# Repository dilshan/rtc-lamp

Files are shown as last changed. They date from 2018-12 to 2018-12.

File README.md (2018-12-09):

# RTC based automatic LED lamp

This is real-time clock based automatic LED lamp which we originally designed to use as night light. This lamp can programmed to turn on and off at the specific time of the day. For example, it can program to turn on at 6 PM on each day and to turn off at 4 AM next day.

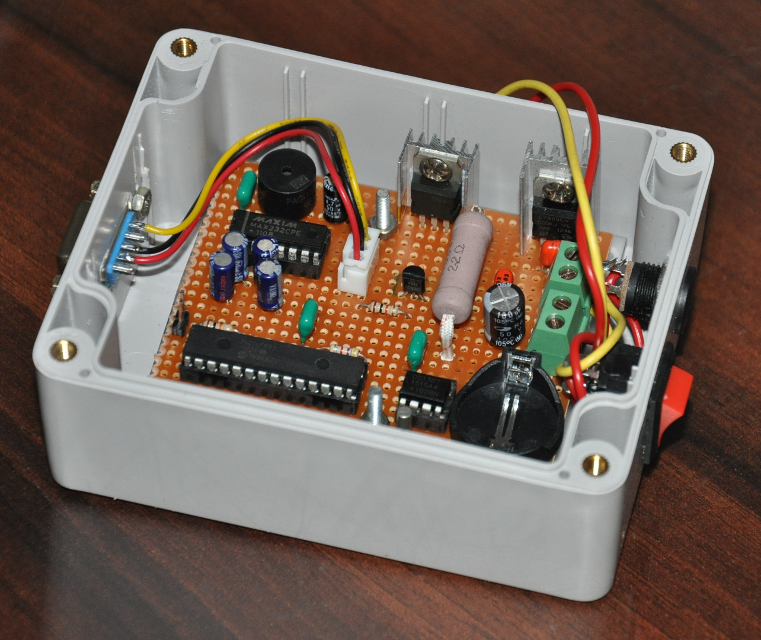
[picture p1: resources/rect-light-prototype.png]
Prototype version of LED lamp


The core component of this project is PIC16F883 MCU and it's firmware is developed using *MikroC Pro for PIC*. We select this MCU because of it's 7 KB flash memory, I2C, UART, E2PROM and built-in 8-bit and 16-bit timers. In this system we use DS1307 RTC because of it's availability in the market and lower external component count.

### LED module

This lamp is designed to work with commonly available 7W LED panels. In our prototype design we use 7W 24V warm-white LED module to test this system. To drive other LED modules change value of the R5 resistor of the current limiter circuit.

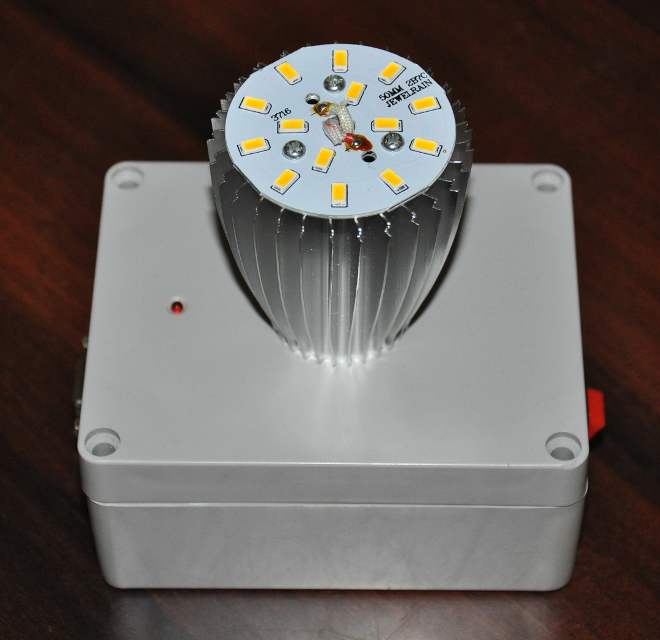
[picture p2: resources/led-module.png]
7W LED module used in prototype build


LED modules, heat-sink and lamp enclosures are now commonly available in the market but make sure to use good quality 24V - 28V LED module with this circuit. During our prototype we found lot of defective LED modules in the market.

### Battery backup

This unit is designed to work with 24V - 3A power supply unit. 3V button cell is required as back power source of DS1307 RTC. Supplied PCB is designed to work with *CR2025* or *CR2032* type button cells.

### Circuit assembly

For this project we use commonly available, less expensive electronic components and PCB is designed for "through-hole" type components. 

Both Q1 (STP55N06) and U4 (LM7805) required heatsinks. If heatsink is shared between both devices make sure to use proper isolation in either Q1 or U4 (or both).

J3 to RS232 pin mapping for DB-9 connector is listed in below:

| J3 | DB9 |
|---|---|
| Pin 1 | Pin 2 |
| Pin 2 | Pin 3 |
| Pin 3 | Pin 5 |

### Firmware

PIC16F883 firmware is developed using *MikroC Pro for PIC*. Compiled HEX file is available at release section of this repository.

### Programming the system

This system is designed to program using RS232 serial port. User can modify system time, light start and end times by connecting this system to any computer through RS232 serial port. To program and view system information user can use any serial terminal application like *minicom*, *putty*, etc. with baud rate of 9600.

Once system is connected to the host PC it can switch to programming mode by sending *Enter* or *Space* key stroke through the serial terminal.

If host PC is not equipped with serial port, use USB to RS232 converter cable / module. During our tests we use couple of USB to RS232 converters (such as *FT232* and *CH340*) without any issues.

### Bill of materials

| Id | Component | Qty |
|---|---|-----|
| U1 | PIC16F883-IP | 1 |
| U2 | DS1307 | 1 |
| U3 | MAX232 | 1 |
| U4 | LM7805 | 1 |
| Q1 | STP55NF06 | 1 |
| Q2 | 2SC945 | 1 |
| D1 | 6A10 | 1 |
| Y1 | 32.768 Crystal | 1 |
| BT1 | CR2025 or CR2032 battery holder with battery | 1 |
| R1, R2, R3 | 4.7K | 3 |
| R4, R6 | 10 K | 2 |
| R5 | 2.2R - 3W | 1 |
| C1 | 4.7 MFD / 16V | 1 |
| C2, C3, C4, C5 | 10MFD / 16V | 4 |
| C6 | 0.33MFD / 63V | 1 |
| C7, C9, C10, C11 | 0.1 MFD / 63V | 4 |
| C8 | 470 MFD / 35V | 1 |
| F1 | 12V 1A Fuse | 1 |
| L1 | VK200 - 3 turns | 1 |
| BZ1 | KXG1203C or 5V DC PCB mount buzzer | 1 |
| J1 | 2.54mm - 2 Way, 1 Row PCB header | 1 |
| J2 | 2.54mm - 3 Way, 1 Row PCB header | 1 |
| J3, J4 | 5.08mm - 2 Way PCB terminal block | 2 |
| | 7W 24V/28V LED module and heatsink | 1 |
| | 3mm Red LED | 1 |
| | DC 50V Rocker switch | 1 |
| | DB9 Female Connector | 1 |
| | Panel Mount DC Power Socket | 1 |
| | TO-220 heatsink | 2 |

### Datasheets

- [PIC16F883 - 28-Pin Enhanced Flash-Based, 8-Bit. CMOS Microcontrollers with. nanoWatt Technology.](https://octopart.com/pic16f883-e/sp-microchip-484880?r=sp&s=gf3fl0DDQqu7zfi6Mu1mTg)
- [DS1307 - Serial Real-Time Clock](https://octopart.com/ds1307+-maxim+integrated-998915?r=sp&s=hPqOpBiTSiaPCVOwAzWNwA)
- [MAX232 - 5V-Powered, Multichannel RS-232 Drivers/Receivers](https://octopart.com/max232cpe-maxim+integrated-55450068?r=sp&s=dPfpbiRnRZ2jJNLkmzmRFQ)
- [LM7805 - 3-Terminal, 1A Positive Voltage Regulator.](https://octopart.com/lm7805ct/nopb-texas+instruments-23919374?r=sp&s=__mIdAy-R1qIqddPHdqk4g)
- [STP55NF06 - N-CHANNEL 60V - 50A Power MOSFET](https://octopart.com/stp55nf06-stmicroelectronics-335317?r=sp&s=E7hGFTBFSqqGf4v1k2f-rA)
- [2SC945 - NPN Silicon Transistor](https://octopart.com/2sc945a-a-renesas-66523934?r=sp&s=pYvJG4XtT0ekf6kEQFJn-A)
- [6A10 - 1000 V - 6 A High Surge Current Silicon Rectifier](https://octopart.com/6a10-t-diodes+inc.-55426548?r=sp&s=7SjnoxDITDCXdY6NPBmLIg)

### License

This is an open hardware project and all it's source code are released under the terms of [MIT license](https://opensource.org/licenses/MIT). Schematics, PCB designs and other resources are released under the terms of [Creative Commons Attribution 4.0 international](https://creativecommons.org/licenses/by/4.0/) license.

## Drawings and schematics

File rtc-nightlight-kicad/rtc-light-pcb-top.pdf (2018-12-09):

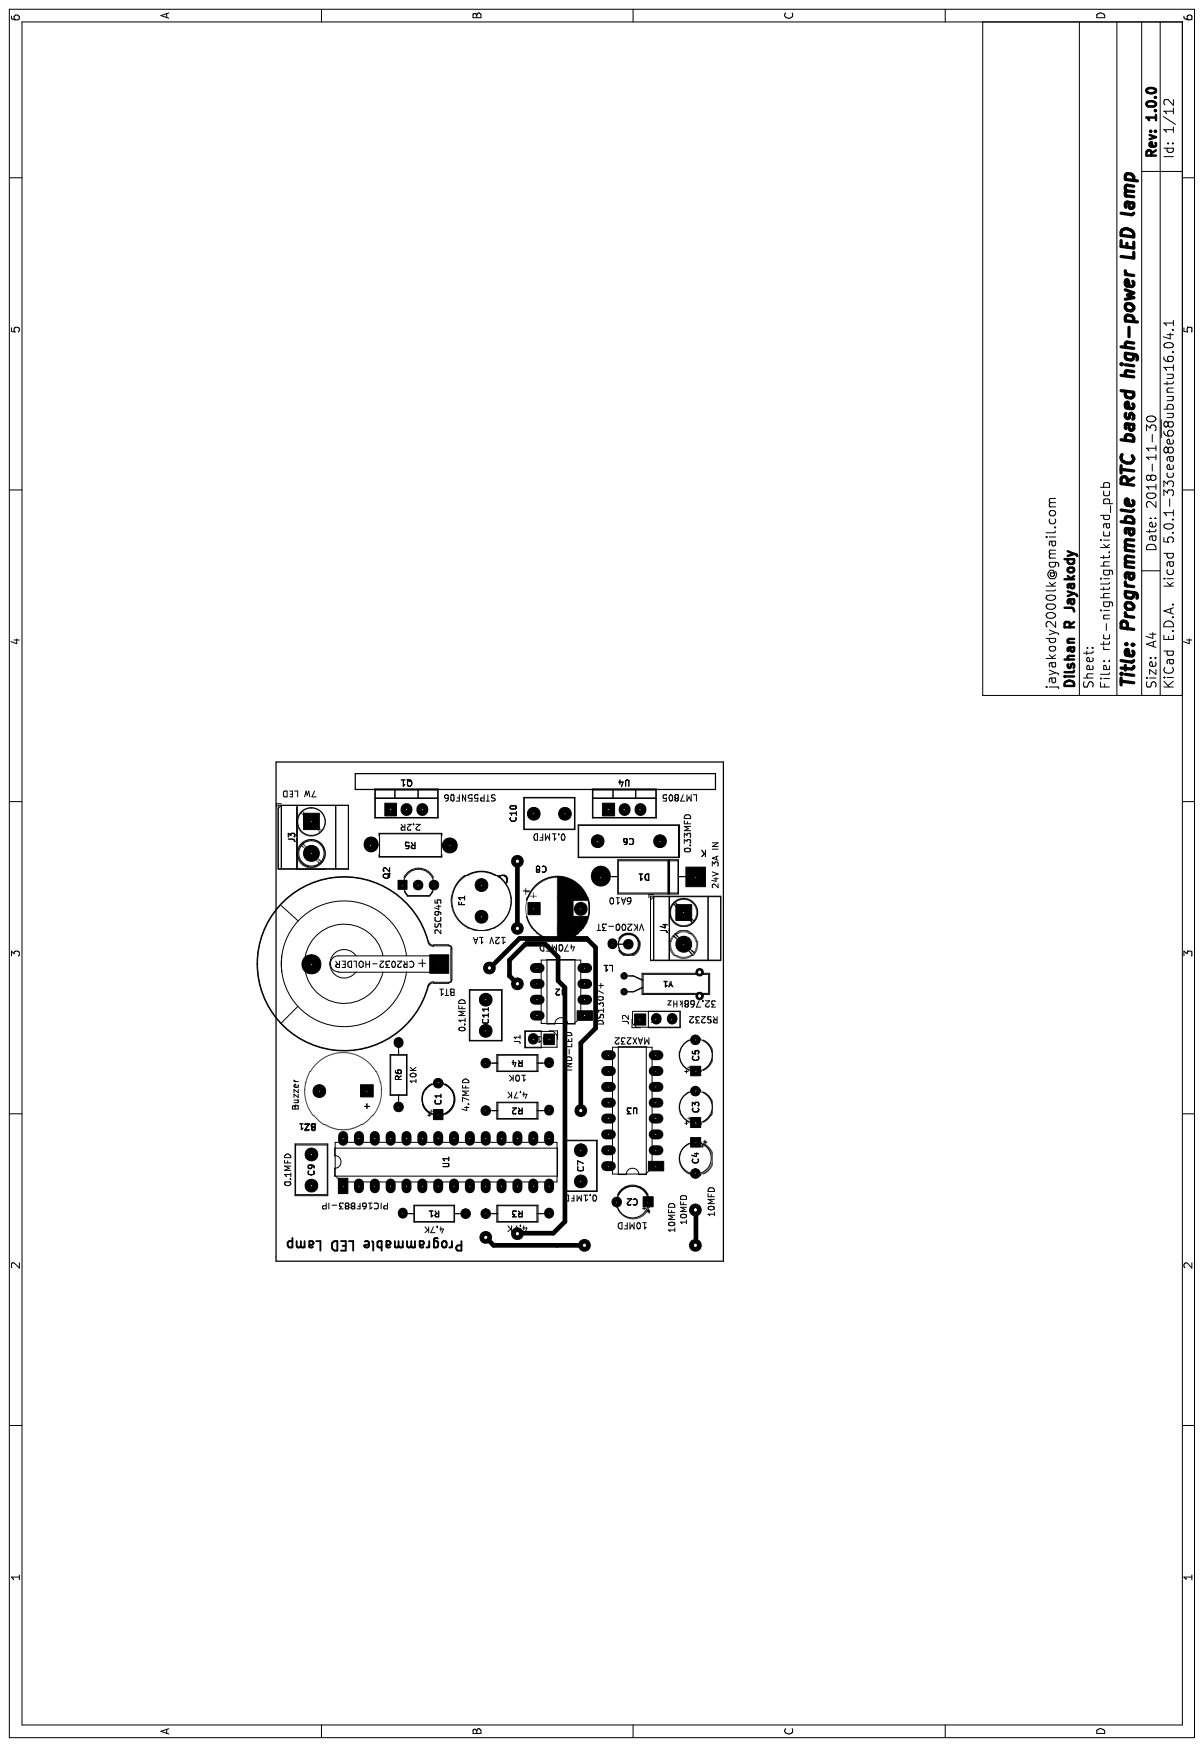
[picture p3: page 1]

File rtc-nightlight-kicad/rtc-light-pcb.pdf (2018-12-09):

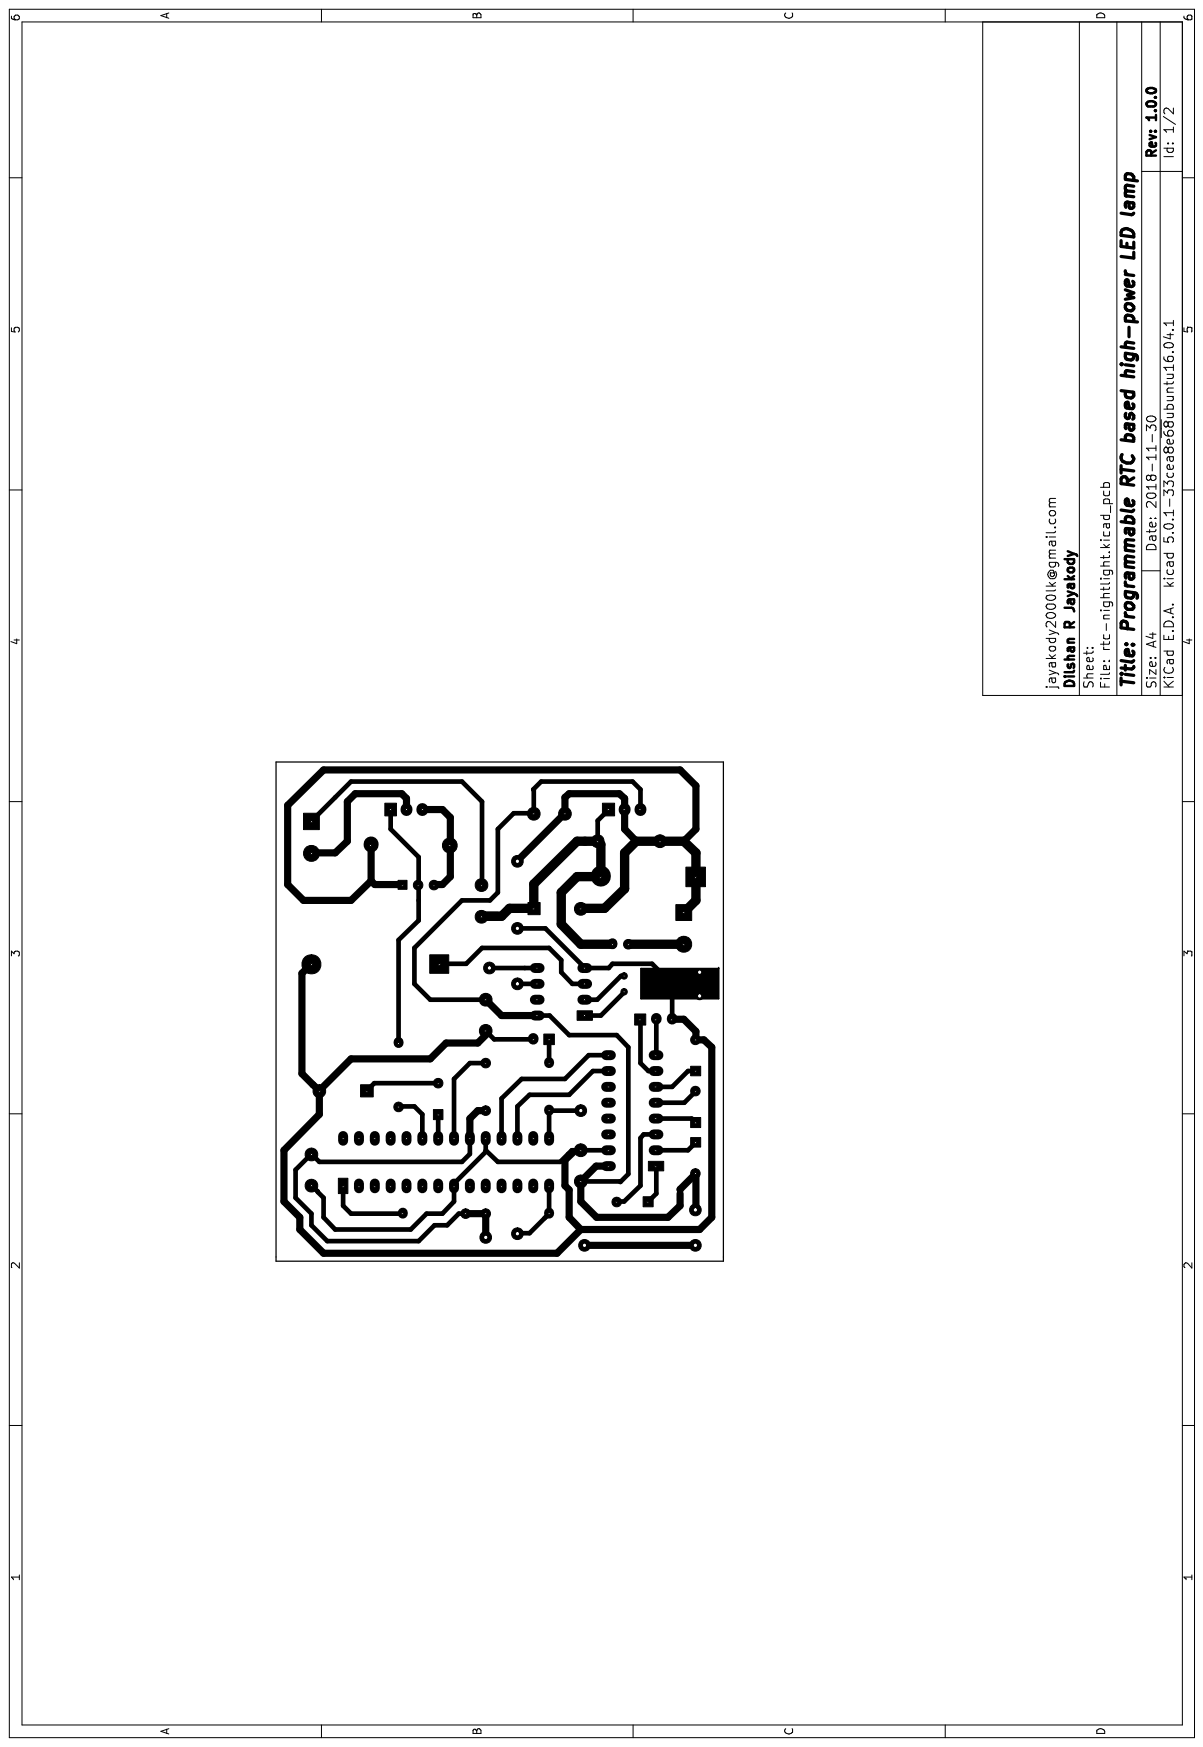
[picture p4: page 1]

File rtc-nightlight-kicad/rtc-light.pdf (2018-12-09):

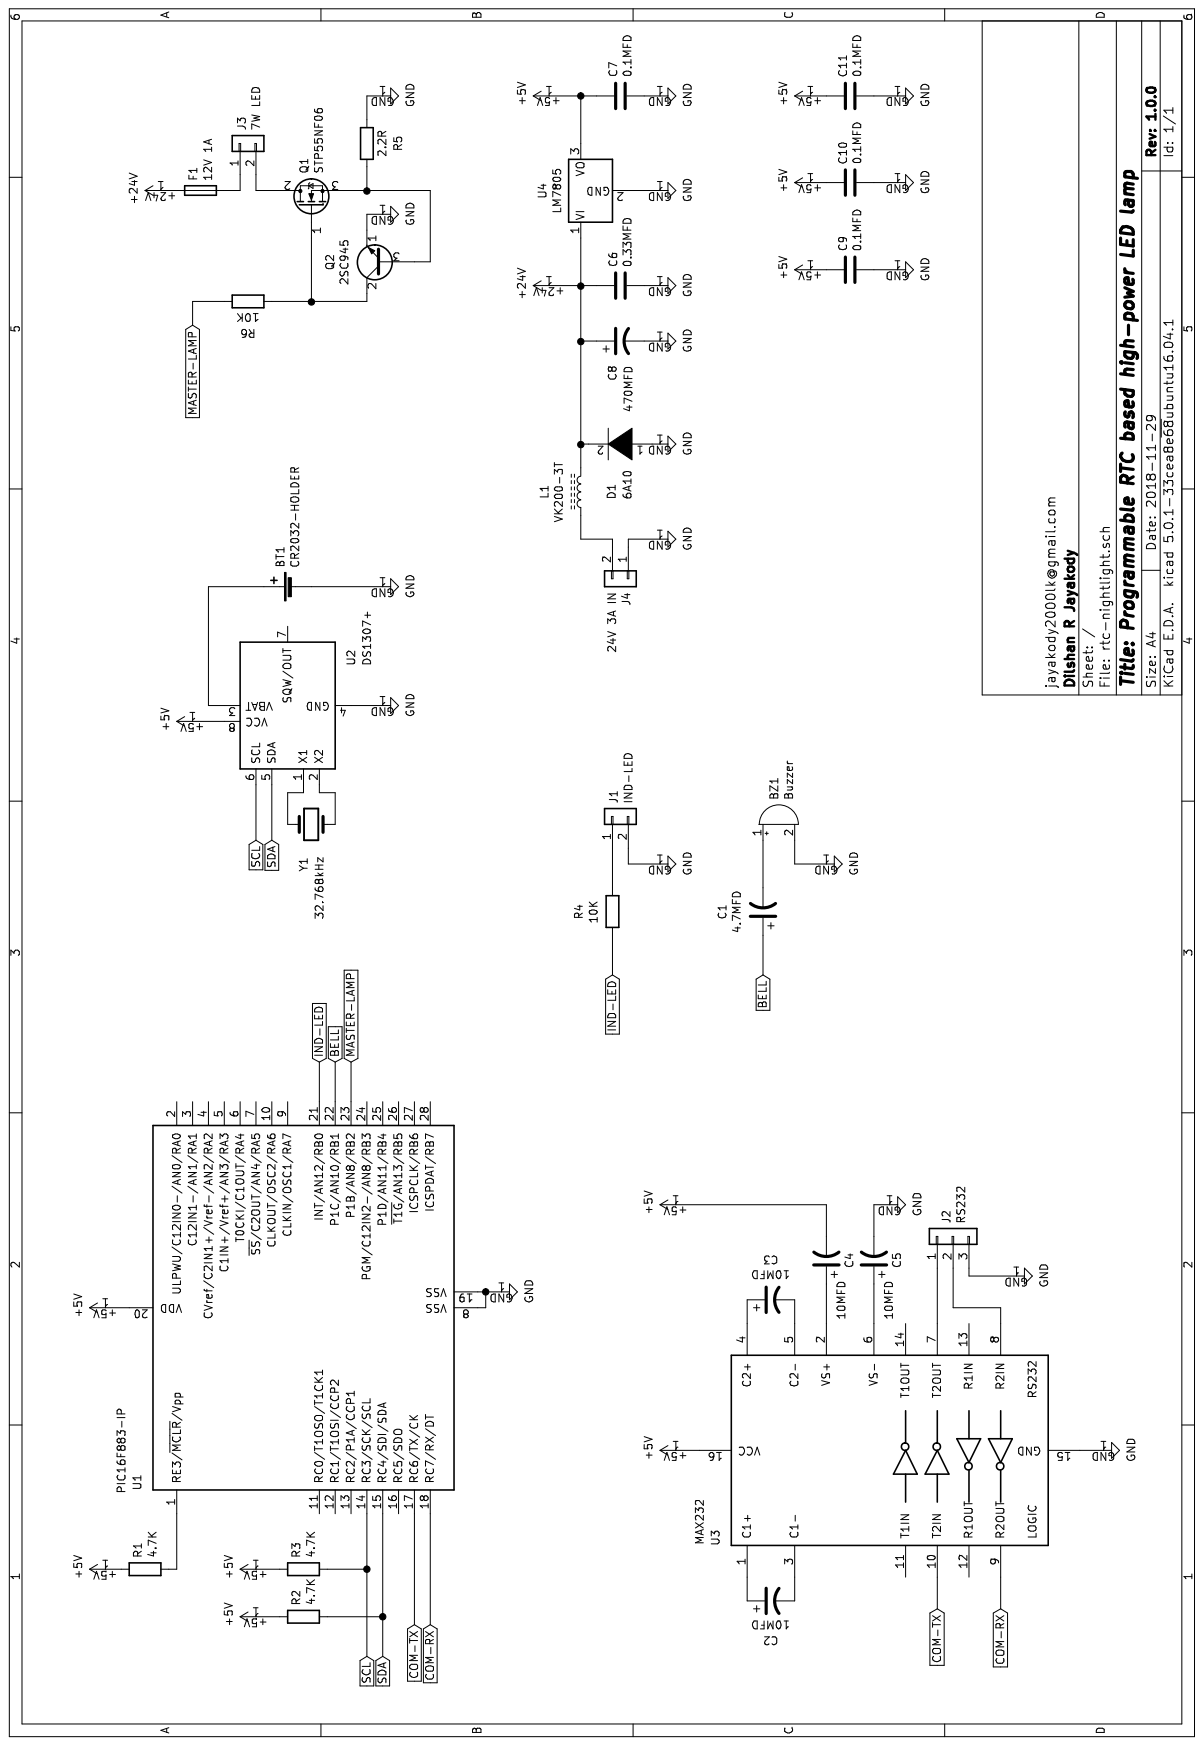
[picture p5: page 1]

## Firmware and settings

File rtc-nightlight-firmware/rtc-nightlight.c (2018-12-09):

// ***************************************************************************
// RTC based automatic LED lamp - PIC16F883 Firmware.
//
// Copyright (c) 2018 Dilshan R Jayakody.
//
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
#include "rtc-nightlight.h"

void main()
{
   char uartData = 0;
   unsigned char lightState, lightOut;

   // Initialize system registers and peripherals.
   initSystem();
   loadLightSettingsFromE2PROM();
   
   _rtcLock = 0;
   _idleCounter = 0;
   _msCounter = 0;
   _checkFlag = 0;
   _programIndCounter = 0;
   _programInd = 0;
   
   // Generate initial startup beeps.
   Sound_Play(1000, 250);
   Delay_ms(100);
   Sound_Play(1250, 250);
   
   while(1)
   {
      // Check for any data in serial buffer to enter into configuration options.
      if (UART1_Data_Ready())
      {
         uartData = UART1_Read();
         // Configuration option is allow for <ENTER> or <SPACE> key strokes.
         if((uartData == 0x20) || (uartData == 0x0D))
         {
            initSystemConfiguration();
         }
         else
         {
           // For non <ENTER> or <SPACE> key strokes show time and quick help.
           UART1_Write_Text(copyToRam(intoHelp1));
           UART1_Write_Text(copyToRam(intoHelp2));
         }
      }
      
      // Check for system time update flag.
      if(_checkFlag == 0xFF)
      {
         _checkFlag = 0x00;
         getSystemTime();
         lightState = isLightActive();
         
         // Beep if state change occured.
         if(lightState != _lastLightStatus)
         {
            Sound_Play(1000, 150);
            Delay_ms(75);
            Sound_Play(1250, 150);
            
            _lastLightStatus = lightState;
         }
         
         // Update state of the main lamp and status LED.
         lightOut = (lightState == FAIL) ? 0x00 : 0x01;
         PORTB = (PORTB & 0xFA) |  ((lightOut << 2) | ((!lightOut) & 0x01));
      }
   }
}

void Interrupt()
{
   // Check for TIMER01 interrupts.
   if(TMR1IF_bit)
   {
      if((++_programIndCounter) == 2)
      {
         // Flash status LED to indicate programming mode.
         _programIndCounter = 0;
         _programInd = (_programInd == 0x00) ? 0x01 : 0x00;
         PORTB = (PORTB & 0xFE) | _programInd;
         
         // Increase idle counter.
         if((++_idleCounter) == 60)
         {
            // Getting ready to restart the system.
            disableBlinkTimer();
            
            // Reset system to leave the programming mode.
            PCLATH = 0x00;
            PCL = 0x00;
         }
      }
      // Start TIMER01 again.
      TMR1IF_bit = 0;
      TMR1H = 0x0B;
      TMR1L = 0xDC;
   }
   
   // Check for TIMER0 Interrupt.
   if(TMR0IF_bit)
   {
      TMR0IF_bit = 0x00;
      TMR0 = 0x3D;
      
      // Raise flag to update the system time.
      if((++_msCounter) == 20)
      {
         _msCounter = 0;
         _checkFlag = 0xFF;
      }
   }
}

void enableBlinkTimer()
{
   _programIndCounter = 0;
   _programInd = 0;
   
   // Set TIMER01 to get trigger in 500ms intervals.
   T1CON = 0x31;
   TMR1IF_bit = 0;
   TMR1H = 0x0B;
   TMR1L = 0xDC;
   TMR1IE_bit = 1;
}

void disableBlinkTimer()
{
   _programIndCounter = 0;
   _programInd = 0;
   
   T1CON = 0x00;
}

void setRTCRegister(char address, char value)
{
   I2C1_Start();
   I2C1_Wr(0xD0);
   I2C1_Wr(address);
   I2C1_Wr(value);
   I2C1_Stop();
}

char* copyToRam(const char* inText)
{
   static char returnBuffer[32];
   unsigned char pos = 0;
   for(pos = 0; returnBuffer[pos] = inText[pos]; pos++);
   return returnBuffer;
}

void showError()
{
   Sound_Play(1500, 250);
   UART1_Write_Text(copyToRam(errorNumber));
}

unsigned char getNumber()
{
   unsigned char inBuffer[2];
   unsigned char pos = 0;
   
   // Capture numbers from the user input.
   while(1)
   {
      if(UART1_Data_Ready())
      {
         inBuffer[pos] = UART1_Read();
         if((inBuffer[pos] > 0x2F) && (inBuffer[pos] < 0x3A))
         {
            UART1_Write(inBuffer[pos]);
            if((++pos) == 2)
            {
               break;
            }
         }
         
         // Reset idle counter.
         _idleCounter = 0x00;
      }
   }
   
   // Convert string to a number.
   return ((inBuffer[0] - 0x30) * 10) + (inBuffer[1] - 0x30);
}

unsigned char setTimeToStruct(struct timeStruct *timeVal)
{
   unsigned char inVal;
   UART1_Write_Text(copyToRam(inputTimeFormat));
   
   // Process hours.
   inVal = getNumber();
   if(inVal > 23)
   {
       showError();
       return FAIL;
   }
   
   timeVal->hour = inVal;
   UART1_Write(0x3A);
   
   // Process minutes.
   inVal = getNumber();
   if(inVal > 59)
   {
       showError();
       return FAIL;
   }
   
   timeVal->minute = inVal;
   UART1_Write(0x3A);
   
   // Process seconds.
   inVal = getNumber();
   if(inVal > 59)
   {
       showError();
       return FAIL;
   }
   
   timeVal->sec = inVal;
   return SUCCESS;
}

unsigned char showMainMenu()
{
   char userSelection = 0;
   
   UART1_Write_Text(copyToRam(helpText1));
   UART1_Write_Text(copyToRam(helpText1A));
   UART1_Write_Text(copyToRam(helpText2));
   UART1_Write_Text(copyToRam(helpText3));
   UART1_Write_Text(copyToRam(helpText4));
   UART1_Write_Text(copyToRam(helpText5));
   UART1_Write_Text(copyToRam(helpText6));
   UART1_Write_Text(copyToRam(helpText7));
   UART1_Write_Text(copyToRam(helpText8));

   while(1)
   {
      if(UART1_Data_Ready())
      {
         userSelection = UART1_Read();

         // Wait for valid user input.
         if((userSelection > 0x30) && (userSelection < 0x37))
         {
            UART1_Write(userSelection);
            _idleCounter = 0x00;
            return userSelection - 0x30;
         }
      }
   }
}

void loadLightSettingsFromE2PROM()
{
   // Get light start time from the E2PROM.
   _lightStartTime.hour = EEPROM_Read(0x00);
   _lightStartTime.minute = EEPROM_Read(0x01);
   _lightStartTime.sec = EEPROM_Read(0x02);
   
   // Get light stop time from the E2PROM.
   _lightStopTime.hour = EEPROM_Read(0x03);
   _lightStopTime.minute = EEPROM_Read(0x04);
   _lightStopTime.sec = EEPROM_Read(0x05);
}

void setLightStartTime()
{
   struct timeStruct startTime;
   
   UART1_Write_Text(copyToRam(inputStartTime));
   if(setTimeToStruct(&startTime) == SUCCESS)
   {
      // Write light start time into E2PROM address 0x00-0x02.
      EEPROM_Write(0x00, startTime.hour);
      EEPROM_Write(0x01, startTime.minute);
      EEPROM_Write(0x02, startTime.sec);
      
      // Update system data structure with new configuration.
      _lightStartTime.hour = startTime.hour;
      _lightStartTime.minute = startTime.minute;
      _lightStartTime.sec = startTime.sec;
   }
}

void setLightStopTime()
{
   struct timeStruct stopTime;

   UART1_Write_Text(copyToRam(inputStopTime));
   if(setTimeToStruct(&stopTime) == SUCCESS)
   {
      // Write light stop time into E2PROM address 0x03-0x05.
      EEPROM_Write(0x03, stopTime.hour);
      EEPROM_Write(0x04, stopTime.minute);
      EEPROM_Write(0x05, stopTime.sec);
      
      // Update system data structure with new configuration.
      _lightStopTime.hour = stopTime.hour;
      _lightStopTime.minute = stopTime.minute;
      _lightStopTime.sec = stopTime.sec;
   }
}

void getSystemTime()
{
   // Get RTC time if RTC lock is released, otherwise ignore this call.
   if(_rtcLock == 0)
   {
     I2C1_Start();
     I2C1_Wr(0xD0);
     I2C1_Wr(0);
     I2C1_Start();
     I2C1_Wr(0xD1);

     _sysTime.sec = Bcd2Dec(I2C1_Rd(1));
     _sysTime.minute = Bcd2Dec(I2C1_Rd(1));
     _sysTime.hour = Bcd2Dec(I2C1_Rd(0));

     // Skip day, date, month and year values.
     I2C1_Stop();
   }
}

void setSystemTime()
{
   struct timeStruct sysTime;

   // Set RTC lock to avoid any overlap RTC operations.
   _rtcLock = 1;
   
   UART1_Write_Text(copyToRam(inputSystemTime));
   if(setTimeToStruct(&sysTime) == SUCCESS)
   {
      // Stop RTC oscillator and set new time configuration.
      setRTCRegister(0, 0x80);
      setRTCRegister(1, Dec2Bcd(sysTime.minute));
      setRTCRegister(2, Dec2Bcd(sysTime.hour));
      // We don't care about date, month and year. Lets configure some fixed values to those parameters.
      setRTCRegister(4, 0x01);
      setRTCRegister(5, 0x01);
      setRTCRegister(6, 0x15);
      // Disable SQW output and start oscillator.
      setRTCRegister(7, 0x00);
      setRTCRegister(0, Dec2Bcd(sysTime.sec) & 0x7F);
      
      // Update global data structure.
      _sysTime.sec = sysTime.sec;
      _sysTime.minute = sysTime.minute;
      _sysTime.hour = sysTime.hour;
   }
   
   _rtcLock = 0;
}

void printDigit(unsigned char val)
{
   unsigned char tempDigit = val / 10;
   UART1_Write(tempDigit + 0x30);
   tempDigit = val - (tempDigit * 10);
   UART1_Write(tempDigit + 0x30);
}

void printTimeStructure(struct timeStruct* timeData)
{
   printDigit(timeData->hour);
   UART1_Write(':');
   printDigit(timeData->minute);
   UART1_Write(':');
   printDigit(timeData->sec);
}

void showSystemConfig()
{
   // Show light start time.
   UART1_Write_Text(copyToRam(inputStartTime));
   UART1_Write_Text(copyToRam(valuePointer));
   printTimeStructure(&_lightStartTime);
   
   // Show light stop time.
   UART1_Write_Text(copyToRam(inputStopTime));
   UART1_Write_Text(copyToRam(valuePointer));
   printTimeStructure(&_lightStopTime);
   
   // Show current system time.
   UART1_Write_Text(copyToRam(inputSystemTime));
   UART1_Write_Text(copyToRam(valuePointer));
   getSystemTime();
   printTimeStructure(&_sysTime);
}

void showSystemVersion()
{
   UART1_Write_Text(copyToRam(version1));
   UART1_Write_Text(copyToRam(version2));
   UART1_Write_Text(copyToRam(version3));
   UART1_Write_Text(copyToRam(version4));
}

void initSystemConfiguration()
{
   // Start TIMER01 to blink the status LED.
   enableBlinkTimer();
   
   while(1)
   {
      switch(showMainMenu())
      {
         // Set system time.
         case 0x01:
            setSystemTime();
            break;
            
         // Set start time.
         case 0x02:
            setLightStartTime();
            break;

         // Set end time.
         case 0x03:
            setLightStopTime();
            break;

         // Show system configuration.
         case 0x04:
            showSystemConfig();
            break;
         
         // Show version information of the system.
         case 0x05:
            showSystemVersion();
            break;
            
         // Exit from the configuration system.
         case 0x06:
            UART1_Write('\r');
            UART1_Write('\n');
            // Shutdown TIMER01 and reset status LED.
            disableBlinkTimer();
            PORTB = PORTB & 0xFE;
            return;
            break;
      }
      
      UART1_Write('\r');
      UART1_Write('\n');
   }
}

unsigned long timeToNumber(struct timeStruct* timeData)
{
   unsigned long hour = timeData->hour;
   unsigned long mins = timeData->minute;
   unsigned long sec = timeData->sec;
   
   return (hour << 16) | (mins << 8) | (sec);
}

unsigned char isLightActive()
{
   unsigned long startTime = timeToNumber(&_lightStartTime);
   unsigned long stopTime = timeToNumber(&_lightStopTime);
   unsigned long sysTime= timeToNumber(&_sysTime);

   if (stopTime == startTime)
   {
      // Nothing happens if start and end times are equal.
      return FAIL;
   }
   else if (stopTime > startTime)
   {
      // Start and end time are defined before midnight.
      return (sysTime >= startTime) && (sysTime < stopTime) ? SUCCESS : FAIL;
   }
   if (stopTime == 0x00)
   {
      // Stop time is set to mid night.
      return (sysTime < startTime) ? FAIL : SUCCESS;
   }
   else
   {
       // Start and end time are defined including midnight.
       return (sysTime >= startTime) || (sysTime < stopTime) ? SUCCESS : FAIL;
   }
}

void initSystem()
{
   // Setup system registers to default state.
   TRISB = 0x00;
   PORTB = 0x00;
   ADCON0 = 0x00;
   ANSEL = 0x00;
   ANSELH = 0x00;
   WPUB = 0x00;
   CCP1CON = 0x00;
   CM1CON0 = 0x00;
   CM2CON0 = 0x00;
   INTCON = 0xE0;
   TMR0 = 0x3D;
   OPTION_REG = 0x07;
   
   // Enable I2C and UART communication channels.
   UART1_Init(9600);
   I2C1_Init(100000);
   Sound_Init(&PORTB, 1);
}
